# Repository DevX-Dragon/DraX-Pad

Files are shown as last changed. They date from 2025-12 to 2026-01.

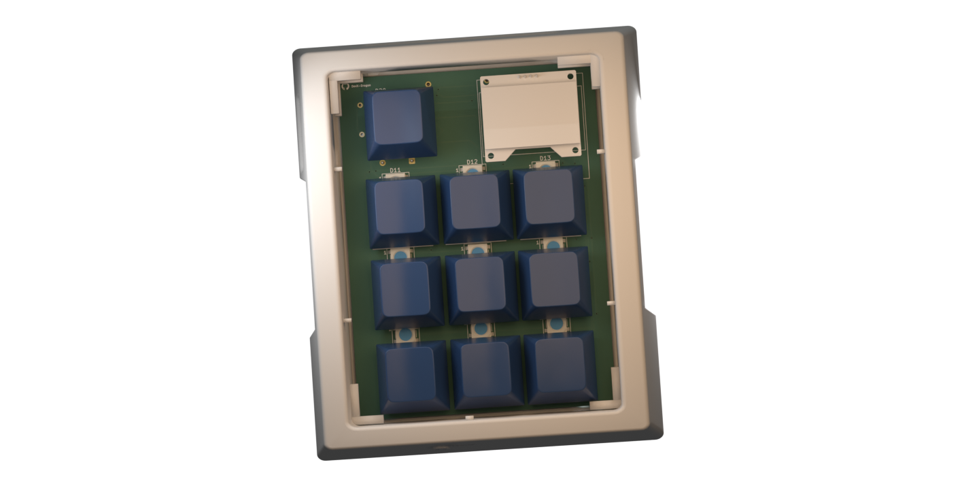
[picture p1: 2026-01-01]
Enclosure Design/Top off render.png

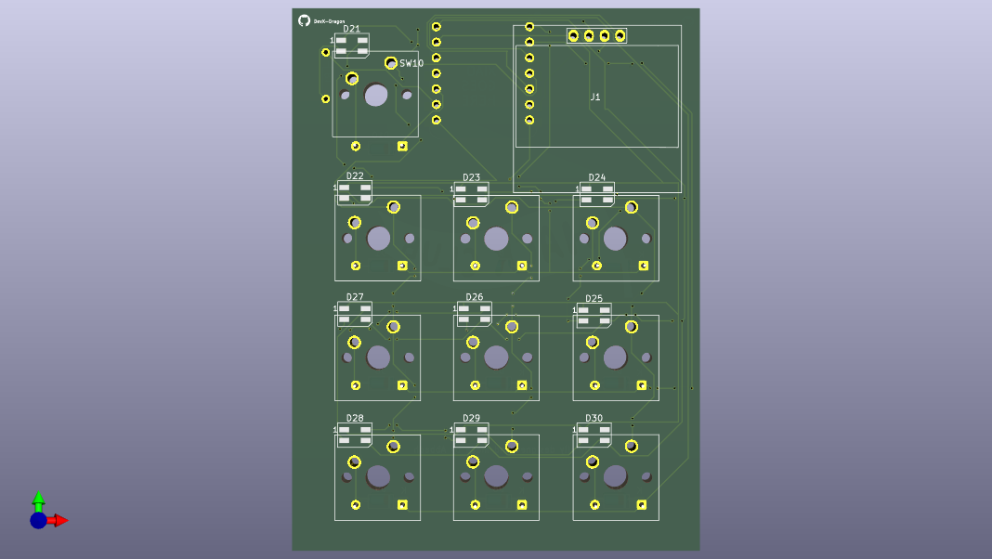
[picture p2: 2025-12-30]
Images/PCB 3D Front.png

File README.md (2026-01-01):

Banner

# **🎮 DraX Pad**
The Ultimate Programmable Macro Pad

Welcome to the DraX Pad project! This is a high-performance, compact macro pad designed for productivity, gaming, and custom control. Powered by the XIAO RP2040, it packs a ton of features into a tiny footprint.

## ✨ Key Features
**⌨️ 10 Programmable Keys:** Fully customizable to launch apps, run complex macros, or control your media.

**⚡ Hot-Swappable:** Change your mechanical switches on the fly—no soldering required.

**📺 0.96" OLED Display:** Real-time feedback, system stats, or even play games directly on your pad using the macro keys.

**🌈 RGB Backlit:** Full per-key RGB lighting for that perfect aesthetic.

**🧠 XIAO RP2040 Powered:** Dual-core ARM Cortex M0+ processor for lightning-fast response times.

**🔌 USB-C Connectivity:** Modern, reliable, and easy to plug in.

**🎛️ Multiple Presets:** Switch between different layers (Gaming, Video Editing, Coding) with a single tap.

## Images (Layouts)
PCB layout

Schematics layout

## Images (Case Render)
2 png

wb
Top off render

## Components Needed

| Component | Quantity | Description |
| :--- | :---: | :--- |
| **Macropad PCB** | 1 | The main circuit board that includes the SK6812 leds (neopixels), diodes, capacitors|
| **Mechanical Switches** | 10 | Cherry MX compatible (3x3 layout + 1 on top left) |
| **Keycaps** | 10 | Any Profiles |
| **Microcontroller** | 1 | Seed Studio Xiao RP2040 or simillar |
| **USB-C Cable** | 1 | Data-capable cable (not just charging) |

> This is a project done for [Hack Club Blueprint Program](https://blueprint.hackclub.com/home)

> Feel free to make your own version and post it online!

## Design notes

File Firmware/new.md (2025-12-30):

# Setup Instructions
## Follow these steps to get your macropad up and running.

### 1. Connect the Hardware
 Plug a USB-C cable from your PC into the macropad. A new external drive (often named RPI-RP2 or similar) should appear on your computer.

### 2. Install CircuitPython
 Download the correct .uf2 file for your board from the CircuitPython website.

Drag and drop the .uf2 file onto the new drive.

The board will automatically reboot, and the drive name will change to CIRCUITPY.

### 3. Flash the Software
Copy all the Python files from this repository directory and paste them directly onto the CIRCUITPY drive.

Note: Ensure code.py is in the root directory of the drive, as this is the file CircuitPython executes on startup.

### 4. Finalize
Unplug the USB-C cable.

Reconnect the cable to initialize the new firmware.

You're now ready to go! Have fun experimenting!

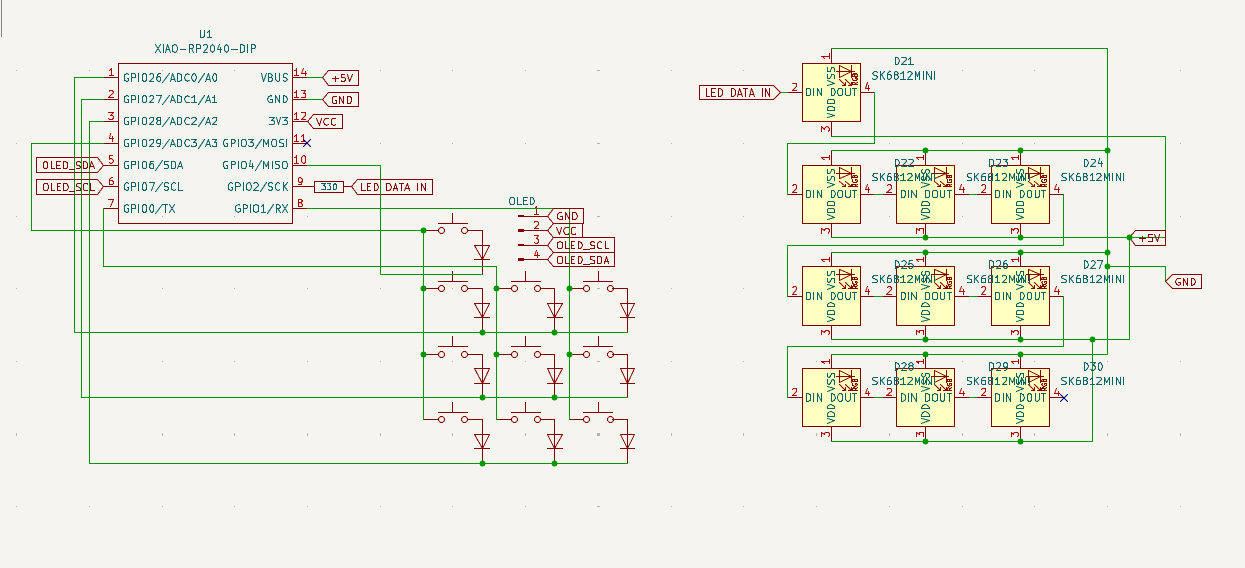
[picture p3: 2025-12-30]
Images/Schematics layout.png

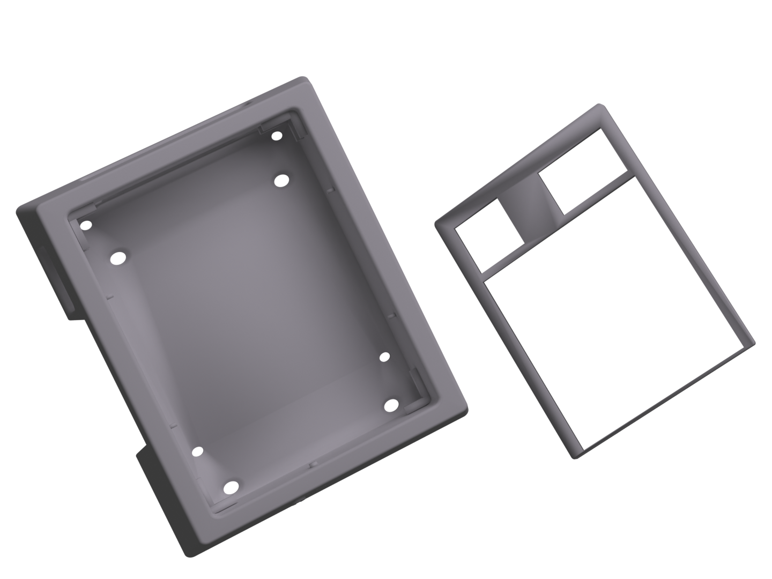
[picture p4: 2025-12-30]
Enclosure Design/Case render 1 (1).png

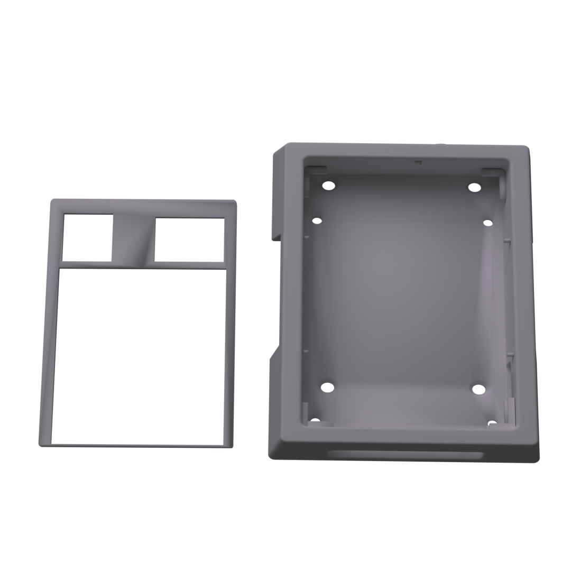
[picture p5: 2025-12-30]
Enclosure Design/Case render (2).png

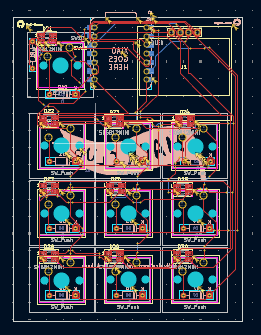
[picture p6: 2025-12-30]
Images/PCB layout.png

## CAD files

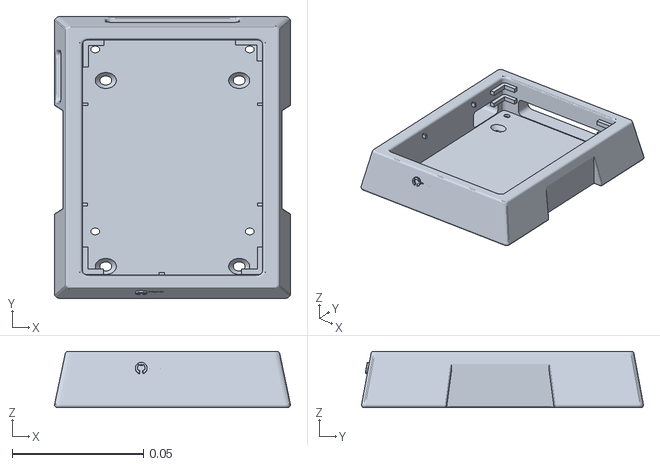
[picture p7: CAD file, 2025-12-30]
Enclosure Design/bottom-case.stl
0.09 x 0.107 x 0.0214

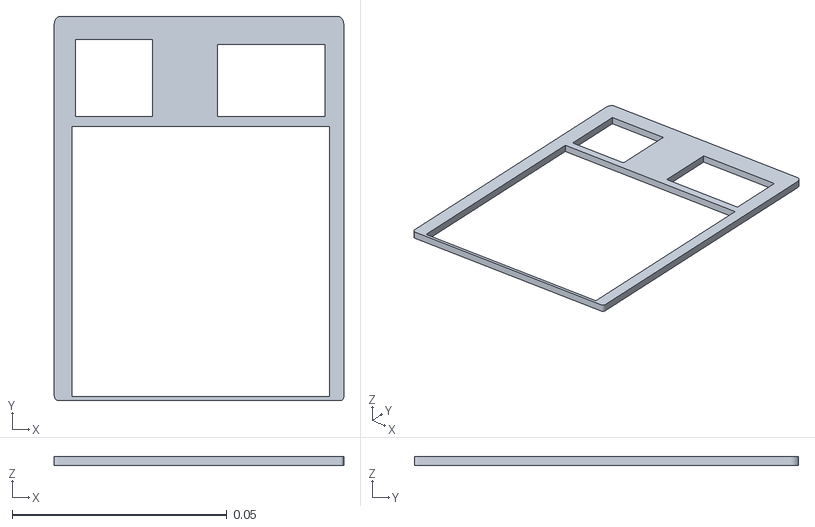
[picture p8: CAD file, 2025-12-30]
Enclosure Design/top-cover.stl
0.0675 x 0.0895 x 0.002

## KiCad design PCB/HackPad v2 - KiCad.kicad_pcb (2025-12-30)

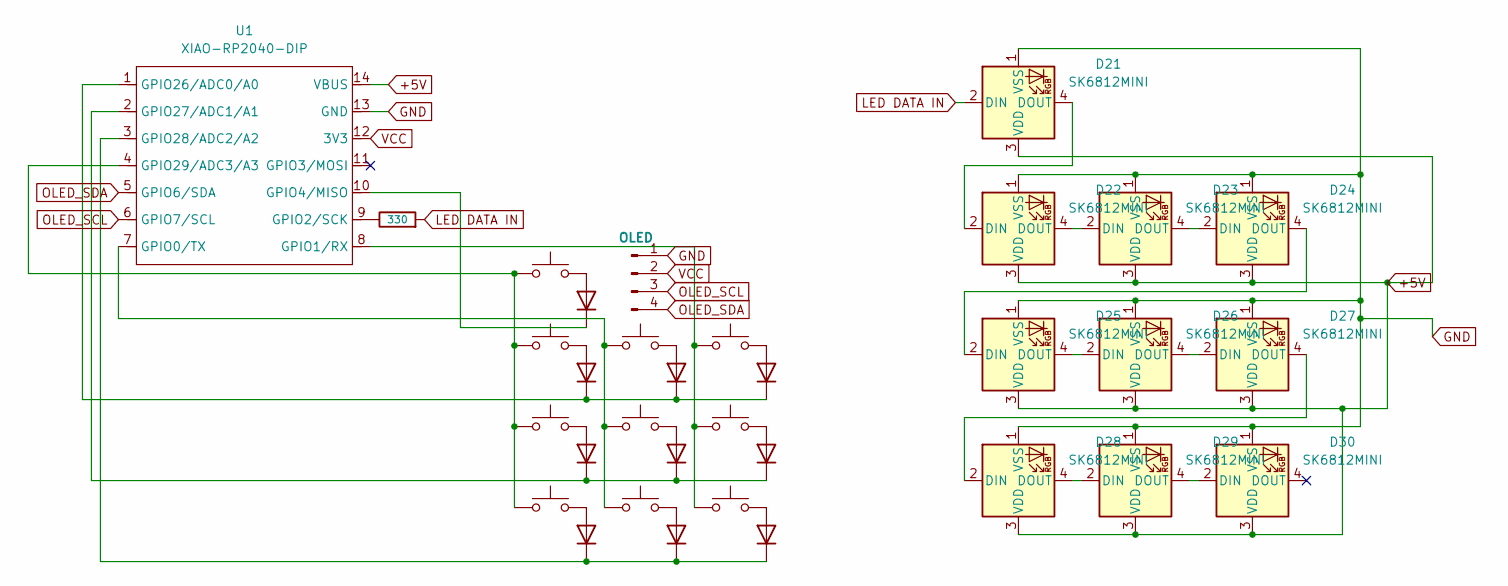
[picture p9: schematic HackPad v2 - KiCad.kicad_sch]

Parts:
D1, D2, D3, D4, D5, D6, D7, D8, D9, D10: D; D_DO-35_SOD27_P7.62mm_Horizontal
D21, D22, D23, D24, D25, D26, D27, D28, D29, D30: SK6812MINI; MX_SK6812MINI-E
J1: OLED; 128x64OLED
R1: 330; R_Axial_DIN0204_L3.6mm_D1.6mm_P7.62mm_Horizontal
SW1, SW2, SW3, SW4, SW5, SW6, SW7, SW8, SW9, SW10: SW_Push; SW_Cherry_MX_1.00u_PCB
U1: XIAO-RP2040-DIP

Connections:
+5V: D21.3 (VDD), D22.3 (VDD), D23.3 (VDD), D24.3 (VDD), D25.3 (VDD), D26.3 (VDD), D27.3 (VDD), D28.3 (VDD), D29.3 (VDD), D30.3 (VDD), U1.14 (VBUS)
GND: D21.1 (VSS), D22.1 (VSS), D23.1 (VSS), D24.1 (VSS), D25.1 (VSS), D26.1 (VSS), D27.1 (VSS), D28.1 (VSS), D29.1 (VSS), D30.1 (VSS), J1.1, U1.13 (GND)
LED DATA IN: D21.2 (DIN), R1.2
unnamed: D1.2 (A), SW1.2
unnamed: D1.1 (K), D2.1 (K), D3.1 (K), U1.1 (GPIO26/ADC0/A0)
unnamed: D2.2 (A), SW2.2
unnamed: D3.2 (A), SW3.2
unnamed: D4.2 (A), SW6.2
unnamed: D4.1 (K), D5.1 (K), D6.1 (K), U1.2 (GPIO27/ADC1/A1)
unnamed: D5.2 (A), SW5.2
unnamed: D6.2 (A), SW4.2
unnamed: D7.2 (A), SW9.2
unnamed: D7.1 (K), D8.1 (K), D9.1 (K), U1.3 (GPIO28/ADC2/A2)
unnamed: D8.2 (A), SW8.2
unnamed: D9.2 (A), SW7.2
unnamed: D10.2 (A), SW10.2
unnamed: D10.1 (K), U1.10 (GPIO4/MISO)
unnamed: D21.4 (DOUT), D22.2 (DIN)
unnamed: D22.4 (DOUT), D23.2 (DIN)
unnamed: D23.4 (DOUT), D24.2 (DIN)
unnamed: D24.4 (DOUT), D25.2 (DIN)
unnamed: D25.4 (DOUT), D26.2 (DIN)
unnamed: D26.4 (DOUT), D27.2 (DIN)
unnamed: D27.4 (DOUT), D28.2 (DIN)
unnamed: D28.4 (DOUT), D29.2 (DIN)
unnamed: D29.4 (DOUT), D30.2 (DIN)
unnamed: SW2.1, SW5.1, SW8.1, U1.7 (GPIO0/TX)
unnamed: SW3.1, SW6.1, SW9.1, U1.8 (GPIO1/RX)
unnamed: R1.1, U1.9 (GPIO2/SCK)
unnamed: SW1.1, SW4.1, SW7.1, SW10.1, U1.4 (GPIO29/ADC3/A3)
OLED_SCL: J1.3, U1.6 (GPIO7/SCL)
OLED_SDA: J1.4, U1.5 (GPIO6/SDA)
VCC: J1.2, U1.12 (3V3)

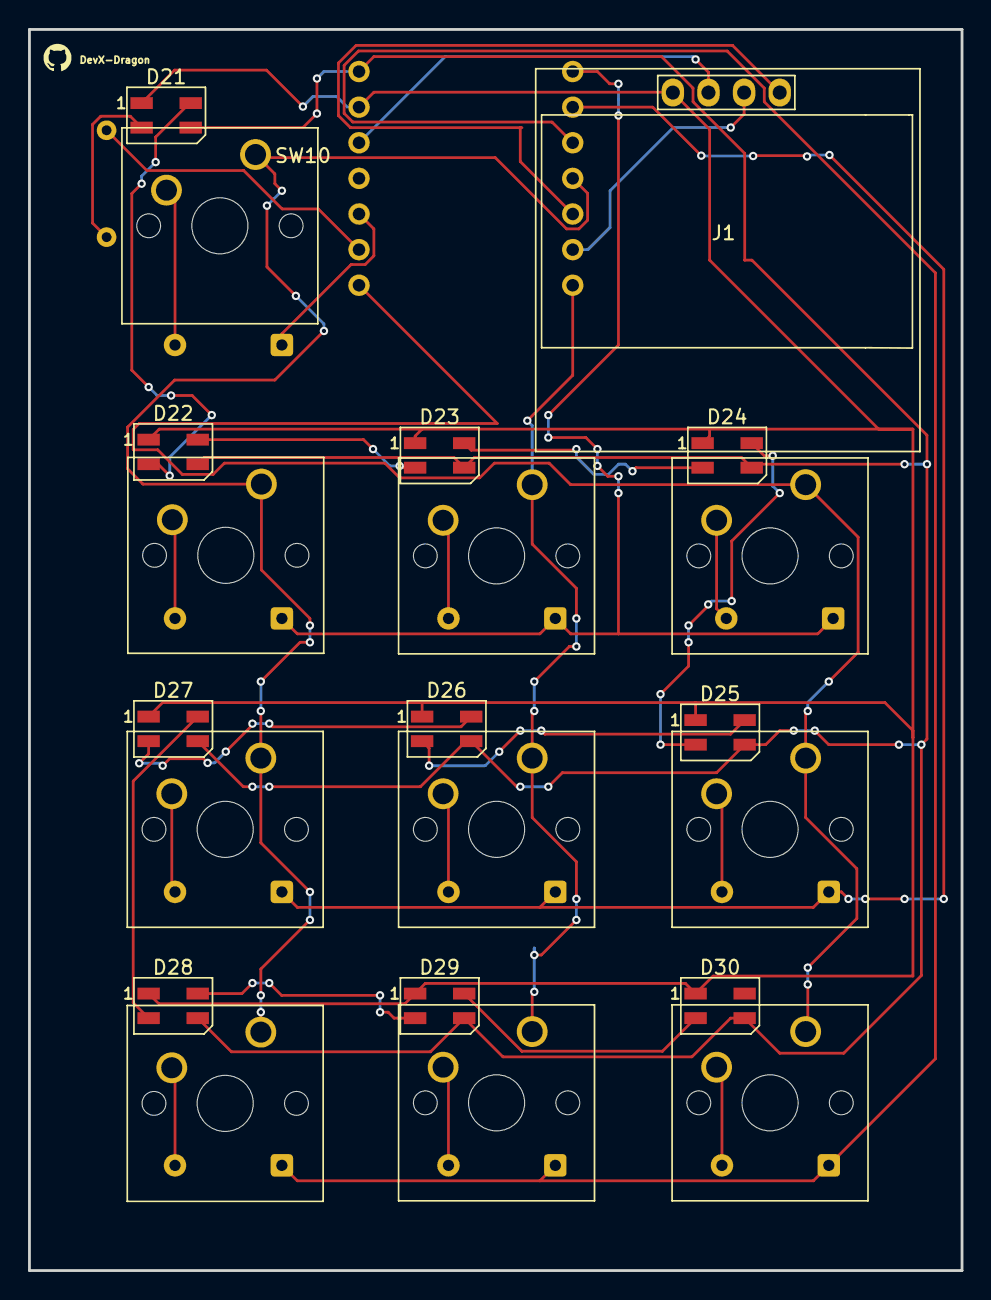
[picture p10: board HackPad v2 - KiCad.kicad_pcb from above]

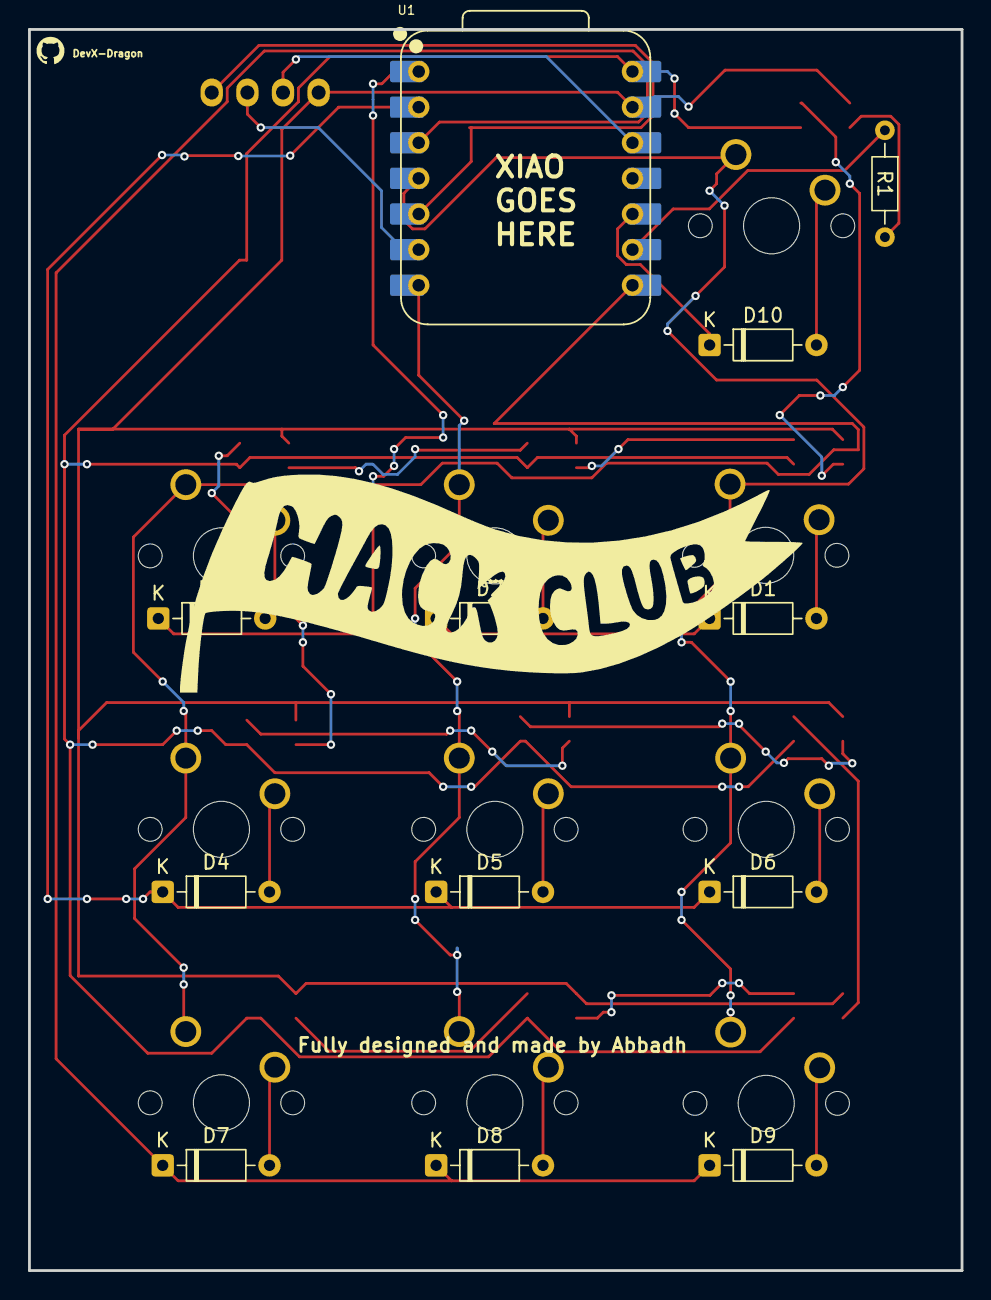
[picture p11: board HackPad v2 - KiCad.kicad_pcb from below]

Board: 2 copper layers, 66.5 x 88.5 mm, 33 parts (12 on the bottom side), 33 nets.

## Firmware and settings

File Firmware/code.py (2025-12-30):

# this code is fully written by me without the use of Ai.
# i have commented out some stuff for ease understanding of others.
# --- DraX Pad V2 Firmware ---
import board, busio, usb_hid, time
import adafruit_ssd1306
import neopixel
from keypad import KeyMatrix
from adafruit_hid.keyboard import Keyboard
from adafruit_hid.keycode import Keycode
# Ensure game_logic.py is present on your CIRCUITPY drive
try:
    from game_logic import MacropadGame
except ImportError:
    MacropadGame = None

# --- Hardware Config (Updated for Final Schematic) ---

# 1. NeoPixels: Using GP2 (Pin 9). 
# Brightness restricted to 0.15 since the capacitor was removed to prevent power spikes.
pixels = neopixel.NeoPixel(board.GP2, 10, brightness=0.15, auto_write=True)

# 2. OLED Display: Now using Hardware I2C on Pins 5 & 6 (GP6/GP7)
# This is much more stable than bit-banging or using the previous noisy pins.
i2c = busio.I2C(board.GP7, board.GP6) # SCL, SDA
display = adafruit_ssd1306.SSD1306_I2C(128, 64, i2c)

# 3. HID Keyboard
kbd = Keyboard(usb_hid.devices)

# 4. Key Matrix (Updated to match the 4x3 layout with GP29)
# Rows: GP29 (Pin 4), GP0 (Pin 7), GP1 (Pin 8), GP7 (Pin 6)
# Columns: GP26 (Pin 1), GP27 (Pin 2), GP28 (Pin 3)
matrix = KeyMatrix(row_pins=(board.GP29, board.GP0, board.GP1, board.GP7), 
                   column_pins=(board.GP26, board.GP27, board.GP28))

# --- Mode Structures ---
MODES = ["MACROS", "RGB", "GAME"]
current_mode_idx = 0
current_preset_idx = 0

PRESETS = [
    {"name": "Work", "keys": {0: [Keycode.A], 1: [Keycode.B], 2: [Keycode.C], 3: [Keycode.D], 4: [Keycode.E], 5: [Keycode.F], 6: [Keycode.G], 7: [Keycode.H], 8: [Keycode.I], 9: [Keycode.J]}},
    {"name": "Gaming", "keys": {0: [Keycode.ONE], 1: [Keycode.TWO], 2: [Keycode.THREE], 3: [Keycode.FOUR], 4: [Keycode.FIVE], 5: [Keycode.SIX], 6: [Keycode.SEVEN], 7: [Keycode.EIGHT], 8: [Keycode.NINE], 9: [Keycode.ZERO]}}
]

if MacropadGame:
    game = MacropadGame(display)
key_states = [False] * 12 

def update_ui():
    display.fill(0)
    display.text(f"MODE: {MODES[current_mode_idx]}", 0, 10, 1)
    if MODES[current_mode_idx] == "MACROS":
        display.text(f"Preset: {PRESETS[current_preset_idx]['name']}", 0, 30, 1)
    display.show()

update_ui()

while True:
    event = matrix.events.get()
    if event:
        key_states[event.key_number] = event.pressed
        
        # Mode Cycling Logic
        if key_states[9] and event.key_number == 0 and event.pressed:
            current_mode_idx = (current_mode_idx + 1) % len(MODES)
            if MODES[current_mode_idx] == "GAME" and MacropadGame: 
                game.reset()
            update_ui()
            continue

        # Preset Cycling Logic
        if event.key_number == 9 and event.pressed and not key_states[0]:
            if MODES[current_mode_idx] == "MACROS":
                current_preset_idx = (current_preset_idx + 1) % len(PRESETS)
                update_ui()
            continue

        # Mode Specific Logic
        if MODES[current_mode_idx] == "MACROS":
            if event.pressed and event.key_number in PRESETS[current_preset_idx]["keys"]:
                kbd.press(*PRESETS[current_preset_idx]["keys"][event.key_number])
                pixels[event.key_number] = (0, 255, 255) # Cyan flash
            elif event.released:
                kbd.release_all()
                pixels.fill(0)

        elif MODES[current_mode_idx] == "GAME" and MacropadGame:
            if event.pressed: 
                game.handle_input(event.key_number)

    if MODES[current_mode_idx] == "GAME" and MacropadGame:
        game.update()
        game.draw()

    time.sleep(0.01) # Reduced sleep for better responsiveness

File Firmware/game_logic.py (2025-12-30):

# this code handles the logic for the games that can be played with the macro keys.
# this is a simple dodge game where you die when the pixel touches you.
# thanks to awesome-macropad repo for game ideas.
import random

class MacropadGame:
    def __init__(self, display):
        self.display = display
        self.reset()

    def reset(self):
        self.player_x = 64
        self.enemy_x = random.randint(0, 120)
        self.enemy_y = 0
        self.score = 0
        self.game_over = False
        self.speed = 2

    def handle_input(self, key_num):
        if self.game_over:
            if key_num == 1: self.reset() # Press middle top key to restart
            return

        if key_num == 0: self.player_x -= 8  # Move Left
        if key_num == 2: self.player_x += 8  # Move Right
        self.player_x = max(0, min(118, self.player_x))

    def update(self):
        if self.game_over: return

        # Enemy falls down
        self.enemy_y += self.speed
        
        # Check if enemy hit the bottom
        if self.enemy_y > 64:
            self.enemy_y = 0
            self.enemy_x = random.randint(0, 120)
            self.score += 1
            # Speed up slightly every 5 points
            if self.score % 5 == 0:
                self.speed += 1

        # COLLISION DETECTION (Dodge Logic)
        # If enemy Y is near player Y and X positions overlap
        if self.enemy_y > 45 and abs(self.player_x - self.enemy_x) < 8:
            self.game_over = True

    def draw(self):
        self.display.fill(0)
        if self.game_over:
            self.display.text("GAME OVER!", 35, 20, 1)
            self.display.text(f"Score: {self.score}", 40, 35, 1)
            self.display.text("Press Key 1", 30, 50, 1)
        else:
            # Draw Score
            self.display.text(f"Score: {self.score}", 0, 0, 1)
            # Draw Player (Paddle)
            self.display.fill_rect(self.player_x, 55, 12, 4, 1)
            # Draw Falling Enemy (Square)
            self.display.fill_rect(self.enemy_x, self.enemy_y, 4, 4, 1)
        
        self.display.show()

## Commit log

2025-12-30 Rename wb.png to render with PCB visible.png
2025-12-30 adding case renders
